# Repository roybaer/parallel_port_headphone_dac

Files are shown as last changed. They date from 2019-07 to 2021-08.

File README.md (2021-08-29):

# Parallel Port Headphone DAC

This is a reasonably accurate replica of the early 1990s SoundJr device by SiliconSoft,
a port-powered parallel port DAC that can directly drive 32 ohm headphones.

A comprehensive list of the SoundJr's features can be found on [the manufacturer's website](http://siliconsoft.com/sndjr1.htm).
The drivers for the SoundJr can be found in the [VOGONS Vintage Driver Library](http://www.vogonsdrivers.com/).

## Pictures

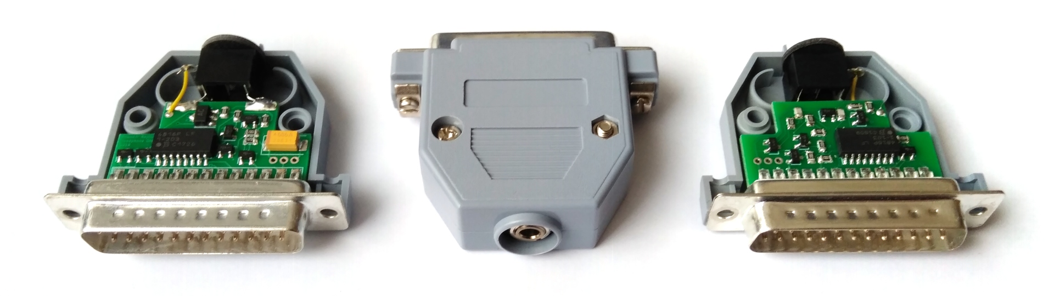
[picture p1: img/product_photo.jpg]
Product photo showing three devices: Front exposed, fully closed, back exposed


## Audio output

The primitive R-2R DAC will continuously convert the 8-bit PCM sample on the parallel port's data lines.
A PC program can therefore play PCM data by periodically writing PCM samples to the parallel port's data port.

## Volume control

The device's output volume can be set to one of nominally eight levels via the control port bits of the PC's parallel port.
Note that some of these signals are active-low.
There is also an implicit energy saving mode that is active whenever no port pin provides power to the device.

Ctrl 3..0 | Volume level
:---------|:------------
0000      | undefined (weaker 8)
0001      | undefined (weaker 6)
0010      | undefined (weaker 7)
0011      | undefined (weaker 5)
0100      | 8
0101      | 6
0110      | 7
0111      | 5
1000      | undefined (weaker 4)
1001      | undefined (weaker 2)
1010      | undefined (weaker 3)
1011      | muted, if data 1..0 = 0
1100      | 4
1101      | 2
1110      | 3
1111      | 1

## Component Substitution

Since the availability and pricing of components can vary widely over the course of decades, some component substitution can become necessary.
The following substitutions have been tested successfully:

Original component              | Acceptable substitute           | Type of component
:-------------------------------|:--------------------------------|:------------------
DAN202K (ROHM Semiconductor)    | M1MA152WKT1G (ON Semiconductor) | Double diode
767163203G (CTS Corporation)    | 4816P-1-203LF (Bourns Inc.)     | Resistor pack
767163103G (CTS Corporation)    | 4816P-1-103LF (Bourns Inc.)     | Resistor pack
MMST2222A (ROHM Semiconductor)  | MSD601-RT1G (ON Semiconductor)  | NPN transistor
MMST2907A (ROHM Semiconductor)  | MSA1162GT1G (ON Semiconductor)  | PNP transistor

The value of the two filter capacitors is unknown, but 1nF capacitors appear to work well enough.

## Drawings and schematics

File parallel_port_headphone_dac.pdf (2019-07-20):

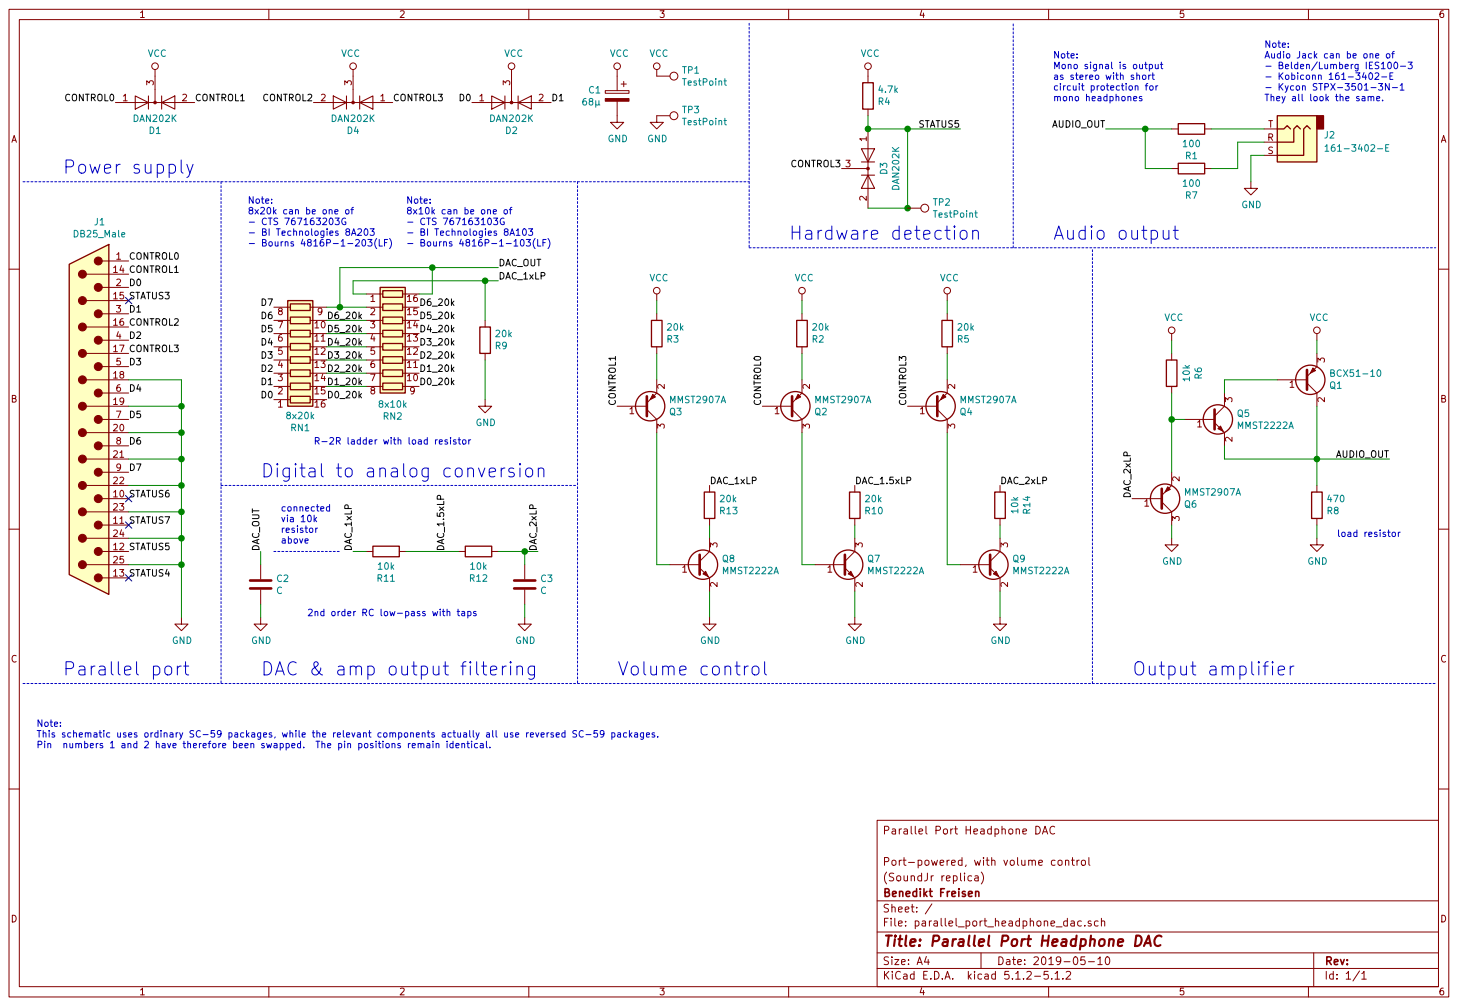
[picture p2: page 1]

Note: Mono signal is output as stereo with short circuit protection for

2 3 Q1BCX51-10 Note: Audio Jack can be one of - Belden/Lumberg IES100-3

3 D4 DAN202K CONTROL2 CONTROL3 R9
mono headphones Note: 8x20k can be one of - CTS 767163203G

They all look the same. R7

R-2R ladder with load resistor Digital to analog conversion

2nd order RC low-pass with taps

Note: This schematic uses ordinary SC-59 packages, while the relevant components actually all use reversed SC-59 packages.

Parallel Port Headphone DAC

Port-powered, with volume control
(SoundJr replica)
File: parallel_port_headphone_dac.sch Sheet: / Benedikt Freisen

Id: 1/1 Title: Parallel Port Headphone DAC

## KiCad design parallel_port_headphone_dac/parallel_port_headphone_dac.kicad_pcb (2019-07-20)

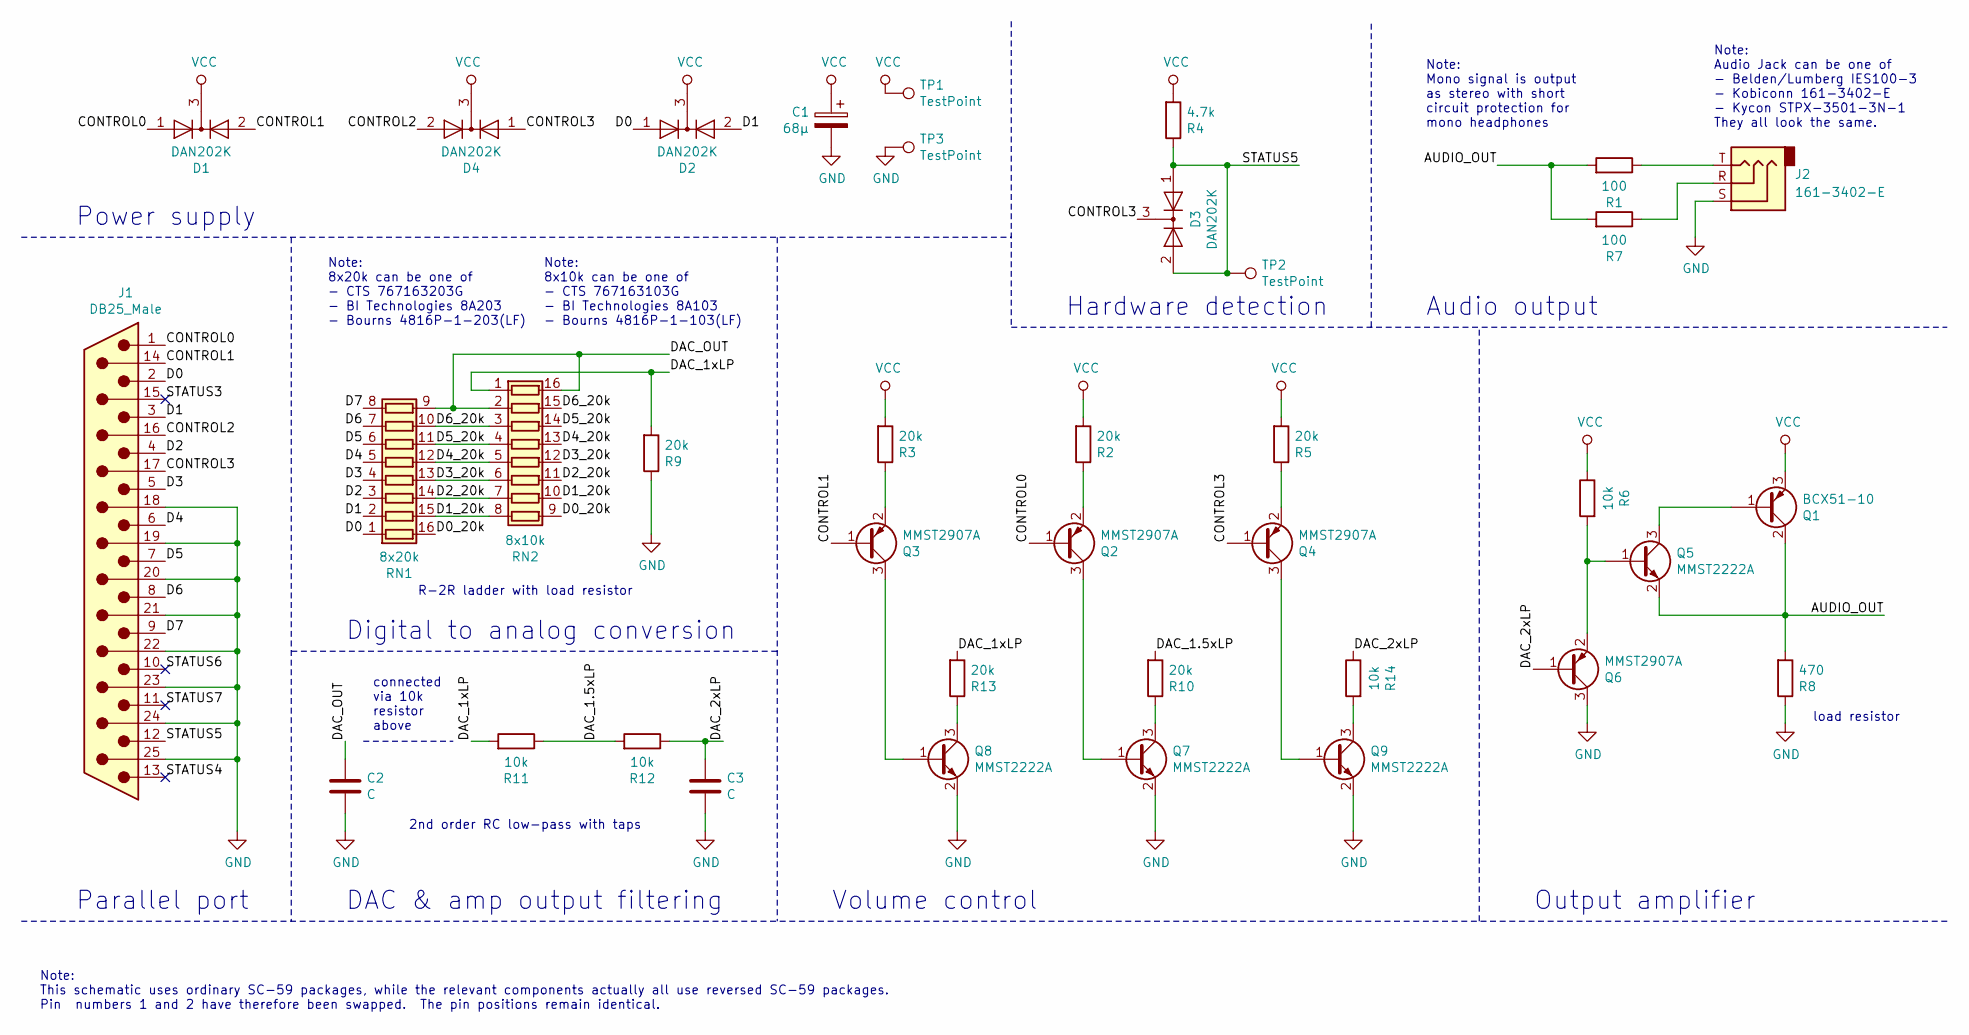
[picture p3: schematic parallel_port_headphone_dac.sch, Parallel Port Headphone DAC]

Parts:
C1: 68µ; CP_EIA-7343-30_AVX-N
C2, C3: C; C_0805_2012Metric
D1, D2, D3, D4: DAN202K; SC-59
J1: DB25_Male; DSUB-25_Male_EdgeMount_P2.77mm
J2: 161-3402-E; SoundJr_AudioJack
Q1: BCX51-10; SOT-89-3
Q2, Q3, Q4, Q6: MMST2907A; SC-59
Q5, Q7, Q8, Q9: MMST2222A; SC-59
R1, R7: 100; R_0805_2012Metric
R2, R3, R5, R9, R10, R13: 20k; R_0805_2012Metric
R4: 4.7k; R_0805_2012Metric
R6, R11, R12, R14: 10k; R_0805_2012Metric
R8: 470; R_0805_2012Metric
RN1: 8x20k; SOIC-16W_5.3x10.2mm_P1.27mm
RN2: 8x10k; SOIC-16W_5.3x10.2mm_P1.27mm
TP1, TP2, TP3: TestPoint; SolderWirePad_1x01_Drill0.8mm

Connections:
/AUDIO_OUT: Q1.2 (C), Q5.2 (E), R1.2, R7.2, R8.2
/CONTROL0: D1.1 (A), J1.1, Q2.1 (B)
/CONTROL1: D1.2 (A), J1.14, Q3.1 (B)
/CONTROL2: D4.2 (A), J1.16
/CONTROL3: D3.3 (K), D4.1 (A), J1.17, Q4.1 (B)
/D0: D2.1 (A), J1.2, RN1.1 (R1.1)
/D0_20k: RN1.16 (R1.2), RN2.9 (R8.2)
/D1: D2.2 (A), J1.3, RN1.2 (R2.1)
/D1_20k: RN1.15 (R2.2), RN2.8 (R8.1), RN2.10 (R7.2)
/D2: J1.4, RN1.3 (R3.1)
/D2_20k: RN1.14 (R3.2), RN2.7 (R7.1), RN2.11 (R6.2)
/D3: J1.5, RN1.4 (R4.1)
/D3_20k: RN1.13 (R4.2), RN2.6 (R6.1), RN2.12 (R5.2)
/D4: J1.6, RN1.5 (R5.1)
/D4_20k: RN1.12 (R5.2), RN2.5 (R5.1), RN2.13 (R4.2)
/D5: J1.7, RN1.6 (R6.1)
/D5_20k: RN1.11 (R6.2), RN2.4 (R4.1), RN2.14 (R3.2)
/D6: J1.8, RN1.7 (R7.1)
/D6_20k: RN1.10 (R7.2), RN2.3 (R3.1), RN2.15 (R2.2)
/D7: J1.9, RN1.8 (R8.1)
/DAC_1.5xLP: R10.2, R11.1, R12.2
/DAC_1xLP: R9.2, R11.2, R13.2, RN2.1 (R1.1)
/DAC_2xLP: C3.1, Q6.1 (B), R12.1, R14.1
/DAC_OUT: C2.1, RN1.9 (R8.2), RN2.2 (R2.1), RN2.16 (R1.2)
/STATUS3: J1.15
/STATUS4: J1.13
/STATUS5: D3.1 (A), D3.2 (A), J1.12, R4.1, TP2.1
/STATUS6: J1.10
/STATUS7: J1.11
GND: C1.2, C2.2, C3.2, J1.18, J1.19, J1.20, J1.21, J1.22, J1.23, J1.24, J1.25, J2.S, Q6.3 (C), Q7.2 (E), Q8.2 (E), Q9.2 (E), R8.1, R9.1, TP3.1
unnamed: J2.R, R7.1
unnamed: J2.T, R1.1
unnamed: Q1.1 (B), Q5.3 (C)
unnamed: Q2.2 (E), R2.1
unnamed: Q2.3 (C), Q7.1 (B)
unnamed: Q3.2 (E), R3.1
unnamed: Q3.3 (C), Q8.1 (B)
unnamed: Q4.2 (E), R5.1
unnamed: Q4.3 (C), Q9.1 (B)
unnamed: Q5.1 (B), Q6.2 (E), R6.2
unnamed: Q7.3 (C), R10.1
unnamed: Q8.3 (C), R13.1
unnamed: Q9.3 (C), R14.2
VCC: C1.1, D1.3 (K), D2.3 (K), D4.3 (K), Q1.3 (E), R2.2, R3.2, R4.2, R5.2, R6.1, TP1.1

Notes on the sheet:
Note: This schematic uses ordinary SC-59 packages, while the relevant components actually all use reversed SC-59 packages. Pin numbers 1 and 2 have therefore been swapped. The pin positions remain identical.
Note: Audio Jack can be one of - Belden/Lumberg IES100-3 - Kobiconn 161-3402-E - Kycon STPX-3501-3N-1 They all look the same.
Power supply
Hardware detection
Parallel port
Note: Mono signal is output as stereo with short circuit protection for mono headphones
Note: 8x20k can be one of - CTS 767163203G - BI Technologies 8A203 - Bourns 4816P-1-203(LF)
Note: 8x10k can be one of - CTS 767163103G - BI Technologies 8A103 - Bourns 4816P-1-103(LF)
2nd order RC low-pass with taps
Volume control
DAC & amp output filtering
Audio output
Output amplifier
load resistor
R-2R ladder with load resistor
Digital to analog conversion
connected via 10k resistor above

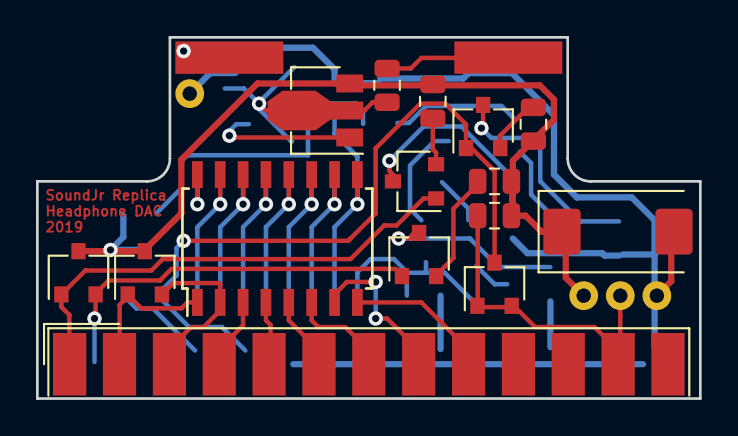
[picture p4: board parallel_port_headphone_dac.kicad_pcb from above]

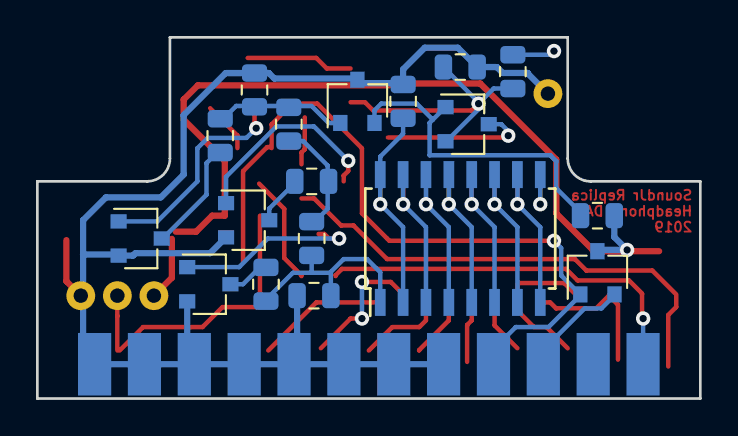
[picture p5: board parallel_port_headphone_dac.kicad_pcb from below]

Board: 2 copper layers, 36.8 x 20.1 mm, 37 parts (18 on the bottom side), 40 nets.
